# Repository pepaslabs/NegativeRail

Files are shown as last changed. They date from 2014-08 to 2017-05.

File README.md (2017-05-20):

# NegativeRail

An ICL7660-based negative rail daughter board.

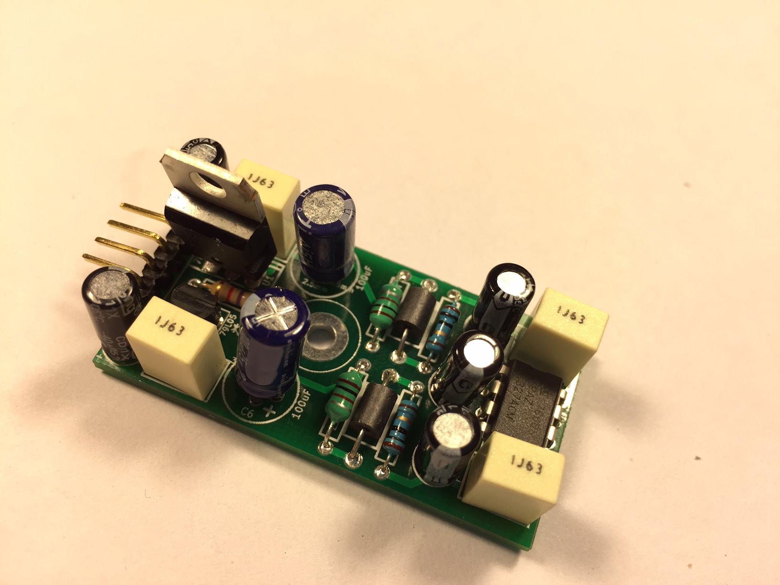
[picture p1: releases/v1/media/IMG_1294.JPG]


# Development

See my eevblog.com [forum thread](https://www.eevblog.com/forum/projects/an-evening-with-the-icl7660/) for lots of oscilloscope screenshots as I tested various iterations of this design.

# Status

This board has been tested using the [dutch oven faraday cage](https://www.eevblog.com/forum/beginners/the-$20-desktop-faraday-cage/):

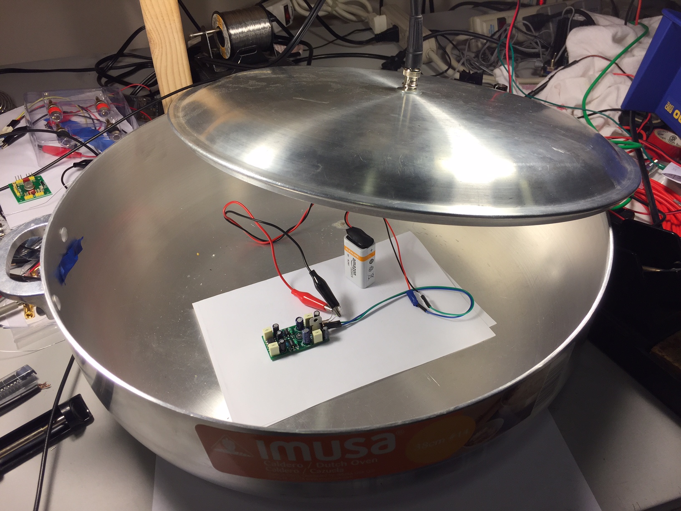
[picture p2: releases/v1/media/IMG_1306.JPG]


Performance matches that of the prototype (see the eevblog.com [forum thread](https://www.eevblog.com/forum/projects/an-evening-with-the-icl7660/)).

Noise into a 1k load:

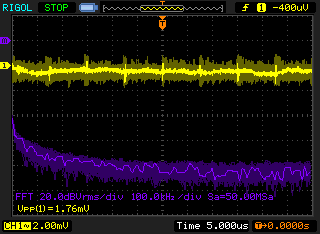
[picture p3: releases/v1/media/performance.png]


Noise with power supply disconnected (i.e., noise floor of measurement system):

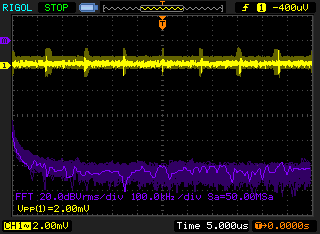
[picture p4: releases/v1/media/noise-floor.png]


This indicates that the ~750kHz spikes are not coming from the ICL7660 board (perhaps this is due to the switch-mode power supply inside of the scope?).

# Board design v1

Initial board design.

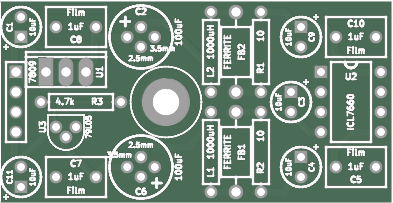
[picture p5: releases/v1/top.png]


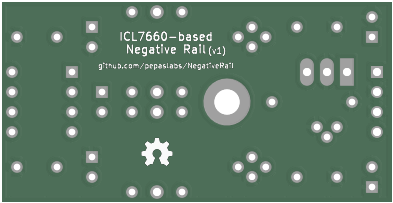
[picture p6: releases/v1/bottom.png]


## Gerbers

[gerbers.zip](releases/v1/gerbers.zip)

## Schematic

[PDF](releases/v1/ICL7660-schematic.pdf).

# License

This board design is [Open-Source Hardware](http://www.oshwa.org/definition/).  It is licensed under the [MIT License](http://opensource.org/licenses/MIT).  It was designed by Jason Pepas.

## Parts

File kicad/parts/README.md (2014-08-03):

KiCADParts
==========

A collection of KiCAD schematic symbols and component footprints which I have created / tweaked / used.

## Design Constraints / Preferred Values / Conventions

* Label size X / size Y / thickness ratio: 1 / 1 / 0.2
 * Preferred component value label size X / size Y / thickness: 0.03" / 0.03" / 0.006"
 * Minimum component value label size X / size Y / thickness: 0.025" / 0.025" / 0.005"
* Outline thickness: 0.01"

## Pads

* Ratios:
 * **_A_**: Size X: 1, Size Y: 1, Offset Y: 0
 * **_B_**: Size X: 1, Size Y: 1.5, Offset Y: 0.25
 * **_C_**: Size X: 1, Size Y: 2, Offset Y: 0

### 0.060" nominal pads

0.059 pads

Pads sized just under 0.060" (allows routing a 0.020" trace without violating DRC).

 * **_059A_**: Size X: 0.059", Size Y: 0.059", Offset Y: 0
 * **_059B_**: Size X: 0.059", Size Y: 0.0885", Offset Y: 0.01475"
 * **_059C_**: Size X: 0.059", Size Y: 0.118", Offset Y: 0

Drill size is 0.032" (the KiCAD default), which is used for:
 * 1/4W resistors
 * small signal diodes
 * ceramic and small electrolytic capacitors
 * DIP leads
 * TO-92 leads

### 0.070" nominal pads

0.069 pads

Pads sized just under 0.070" (allows routing a 0.010" trace without violating DRC).

 * **_069A_**: Size X: 0.069", Size Y: 0.069", Offset Y: 0
 * **_069B_**: Size X: 0.069", Size Y: 0.1035", Offset Y: 0.01725"
 * **_069C_**: Size X: 0.069", Size Y: 0.138", Offset Y: 0

Drill size is 0.040", which is used for:
 * 1/2W resistors
 * TO-220 leads

### 0.080" nominal pads

0.079 pads

Pads sized just under 0.080" (does not allow routing traces).

 * **_079A_**: Size X: 0.079", Size Y: 0.079", Offset Y: 0
 * **_079B_**: Size X: 0.079", Size Y: 0.1185", Offset Y: 0.01975"
 * **_079C_**: Size X: 0.079", Size Y: 0.158", Offset Y: 0

Drill size is 0.056", which is used for:
 * TO-218 leads
 * TO-247 leads

## Footprints

resistors_PL.mod

DIP_PL.mod

transistors_PL.mod

TO-220_PL.mod

## License

Parts which I have created are released under the [MIT License](http://opensource.org/licenses/MIT).  Parts which I have modified are subject to their original license.

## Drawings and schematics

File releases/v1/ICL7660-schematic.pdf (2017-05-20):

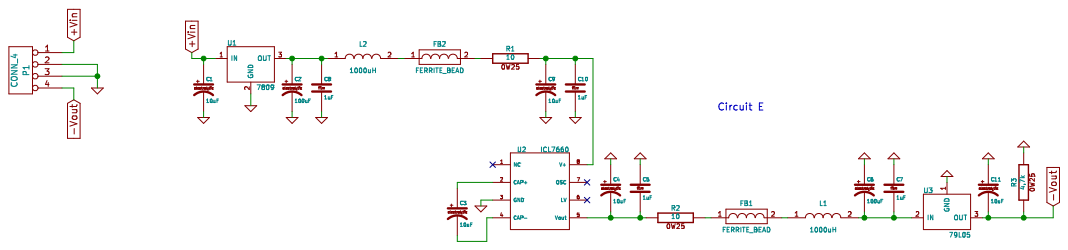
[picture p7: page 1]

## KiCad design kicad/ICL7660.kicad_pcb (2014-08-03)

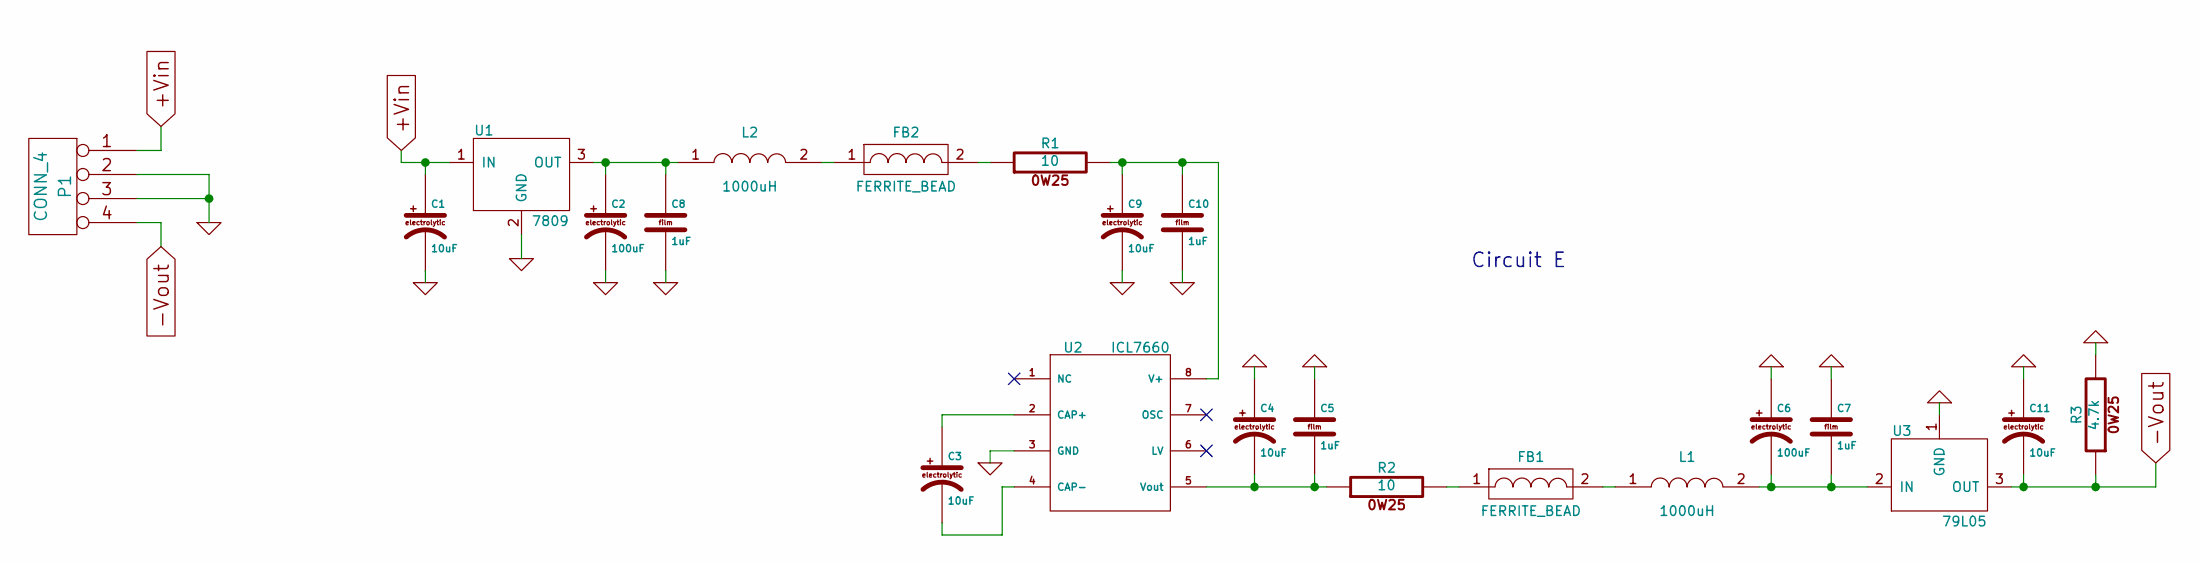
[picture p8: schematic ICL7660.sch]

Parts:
C1, C3, C4, C9, C11: 10uF
C2, C6: 100uF
C5, C7, C8, C10: 1uF
FB1, FB2: FERRITE_BEAD
L1, L2: 1000uH
P1: CONN_4
R1, R2: 10
R3: 4.7k
U1: 7809
U2: ICL7660
U3: 79L05

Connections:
+Vin: C1.1, P1.1, U1.1 (IN)
-Vout: C11.2, P1.4, R3.1, U3.3 (OUT)
GND: C1.2, C2.2, C4.1, C5.1, C6.1, C7.1, C8.2, C9.2, C10.2, C11.1, P1.2, P1.3, R3.2, U1.2 (GND), U2.3 (GND), U3.1 (GND)
unnamed: FB2.1, L2.2
unnamed: FB2.2, R1.1
unnamed: FB1.1, R2.2
unnamed: C2.1, C8.1, L2.1, U1.3 (OUT)
unnamed: C3.2, U2.4 (CAP-)
unnamed: C3.1, U2.2 (CAP+)
unnamed: C9.1, C10.1, R1.2, U2.8 (V+)
unnamed: C6.2, C7.2, L1.2, U3.2 (IN)
unnamed: FB1.2, L1.1
unnamed: C4.2, C5.2, R2.1, U2.5 (Vout)

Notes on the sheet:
Circuit E

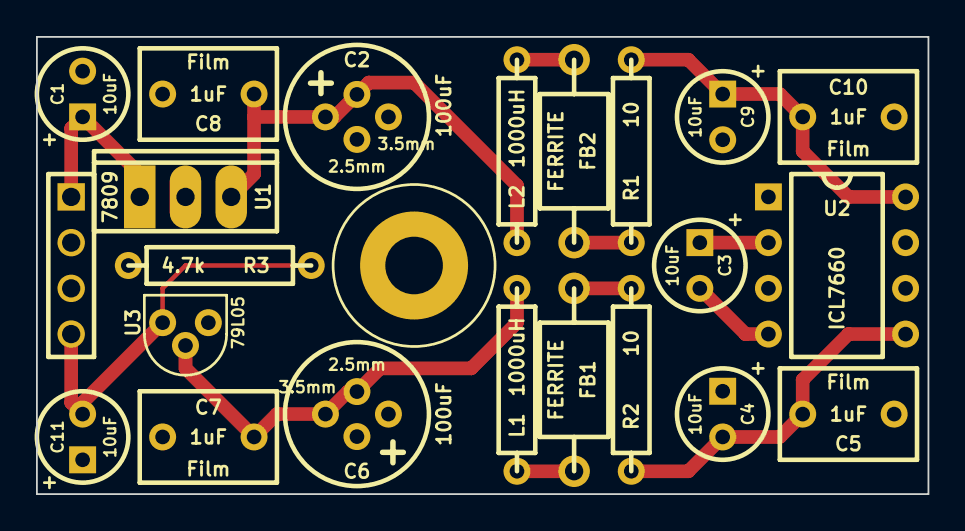
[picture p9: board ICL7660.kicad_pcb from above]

Board: 2 copper layers, 49.5 x 25.4 mm, 23 parts (0 on the bottom side), 13 nets.

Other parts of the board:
H***: Val**; hole_M3

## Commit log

2014-08-03 initial implementation
    [ICL7660.kicad_pcb, ICL7660.sch]
2014-08-03 v1 gerbers
    [ICL7660-B_Cu.gbl, ICL7660-B_Mask.gbs, ICL7660-B_SilkS.gbo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]
2014-08-03 adding OSHW logo to v1 gerbers.
    [ICL7660.kicad_pcb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]
2017-04-22 file organization
    [ICL7660-B_Cu.gbl, ICL7660-B_Mask.gbs, ICL7660-B_SilkS.gbo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]
2017-04-22 adding schematic
2017-05-20 rotating schematic
